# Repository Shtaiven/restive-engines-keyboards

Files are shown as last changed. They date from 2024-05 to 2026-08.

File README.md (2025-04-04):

# restive.engines Keyboards

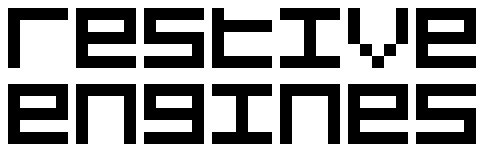
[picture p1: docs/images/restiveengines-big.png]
restiveengines_logo


## Introduction

This repository contains design and manufacturing files created by Steven Eisinger (@Shtaiven a.k.a. restive.engines). Everything you need to manufacture one of my keyboards can be found here, including pcbs, cases, and certain keycaps.

For keyboard firmware, please refer to my [ZMK config repo](https://github.com/Shtaiven/restive-engines-zmk-config).

## Keyboards

### fairyboard

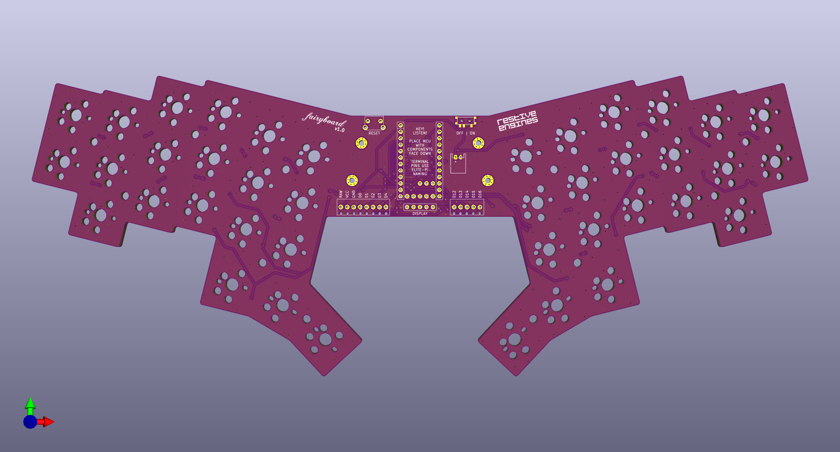
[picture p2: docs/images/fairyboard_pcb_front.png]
fairyboard pcb front


[Build guide](docs/fairyboard.md)

Designed in 2024. Made to address shortcomings and enhance ergonomics of the shockboard. Ergonomic column staggered keyboard extendable with custom modules using terminal blocks or headers. 14 degree rotation on each half. Compatible with MX, Choc v1, and Choc v2 switches.

### shockboard

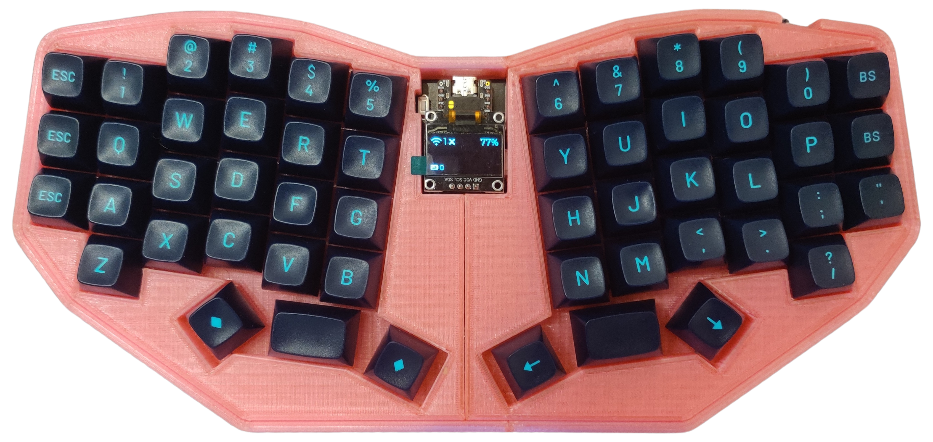
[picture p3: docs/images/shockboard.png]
shockboard_v1_assembled


[Build guide](docs/shockboard.md)

Designed in 2023. My first custom keyboard. Ergonomic column staggered keyboard with a number row, compatible with 1.25u thumb keys. 10 degree rotation on each half. Compatible with MX and Choc v1 switches.

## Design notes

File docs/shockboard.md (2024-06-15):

# shockboard

Assembled shockboard

## Introduction

The shockboard is a monoblock split columnar-staggered keyboard inspired by boards such as the corne, Lily58, Le Chiffre, and others. It is designed based on my own finger positions, with a thumb cluster that is comfortable for my smaller hands while resting in what I consider a neutral position. A monoblock design has been chosen easy portability and setup.

## Manufacturing

### PCB manufacture

See `pcbs/shockboard_v1/shockboard_v1.zip` for files containing pcb fabrication files for each keyboard revision. This zip file can be uploaded to JLCPCB for manufacturing.

### Case manufacture

Only case files for MX switches are currently available in the cases folder.

To print the high profile MX case you will need:

* `cases/shockboard_v1/case_hipro_mx/case_hipro_mx_bottom.stl`
* `cases/shockboard_v1/case_hipro_mx/case_hipro_mx_top.stl`
* `cases/shockboard_v1/pcb_spacer.stl`

These files are provided in both `stl` and `3mf` variants, as well as split into left and right for smaller printers.

## Assembly

### PCB assembly

Materials:

* 1x shockboard PCB
* 1x pro-micro pin compatible microcontroller (nice!nano recommended)
* Mill Max low profile sockets for your micricontroller (see [How do I socket a microcontroller?](https://docs.splitkb.com/hc/en-us/articles/360011263059-How-do-I-socket-a-microcontroller))
* 1x SKHLACA010 footprint compatible button
* 1x MSK12C02 footprint compatible switch
* 52x 1N4148W diodes (SOD-123 surface mount or through-hole)
* 52x CPG151101S11 Kailh hotswap sockets
* 52x MX compatible keyboard switches
* 52x MX compatible keycaps
* 1x SSD1306 OLED display with male and female header pins (optional)
* 1x 301230 LiPo battery with 2-pin JST connector (optional for wireless microcontroller)
* 1x JST 2-pin jack (optional for wireless microcontroller)

Assembling the PCB:

1. Solder the diodes to the back of the PCB (the side with the picture of the cat on it).
2. Solder the Kailh hotswap sockets to the back of the PCB. The hotswap sockets should be oriented such that the bumps fit through the holes and the metal contacts rest on the solder pads.
3. Solder Mill Max low profile female headers to the top side of the PCB in the middle for the microcontroller pins. See [here](https://docs.splitkb.com/hc/en-us/articles/360011263059-How-do-I-socket-a-microcontroller).
4. Socket your microcontroller such that the PCB will lie with its components face-down when attached to the PCB. The microcontroller will be attached from the top of the pcb, so match up the pin labels with those you see on the silkscreen there. See [here](https://docs.splitkb.com/hc/en-us/articles/360011263059-How-do-I-socket-a-microcontroller).
5. Solder the SKHLACA010 button (reset button) to the top of the PCB to the left of the microcontroller.
6. Solder the MSK12C02 switch (power switch) to the top right corner of the PCB.
7. (optional) Solder the 2-pin JST connector to the top side of the board to the right of the microcontroller.
8. (optional) Solder the female headers for the OLED screen to the top side of the board below the microcontroller.
9. (optional) Install the battery into the JST connector and lay in down between the Mill Max headers where the microcontroller will be placed. Make sure that the red battery lead is connected to the left side of the JST jack (marked +) and the black lead is connected to the right side of the JST jack (marked -).
10. Insert the socketed microcontroller with the components faces away from you to the Mill Max sockets.
11. (optional) Insert the OLED display with the pins on the bottom into the female headers.

### Case assembly

Materials:

* 1x case bottom
* 1x case top
* 1x PCB spacer
* 8x m2x8mm screws
* 8x m2 heat-set inserts

Assembling the case:

1. Using a soldering iron, press in the heat-set inserts into the holes of the case bottom from the top-side such that the screws can be screwed in from the top.
2. Create a sandwich with the pieces in the following order from bottom to top:
    1. Case bottom
    2. PCB
    3. PCB spacer
    4. Case top
3. Align the 8 holes of all 4 pieces and screw in the 8 m2 screws from the top of the case until reasonable tight.
4. Insert your favorite switches and keycaps, upload your keyboard firmware, and enjoy!

## Firmware

This keyboard shield has been build with bluetooth-enabled pro-micro compatible boards in mind, like the [nice!nano](https://nicekeyboards.com/nice-nano/).

[ZMK](https://zmk.dev/) support has been added as an [external module](https://zmk.dev/docs/development/build-flash#building-with-external-modules) in my [zmk-config](https://github.com/Shtaiven/shockboard-zmk-config).

For an example of using this with the [miryoku](https://github.com/manna-harbour/miryoku/) layout, see [here](https://github.com/Shtaiven/miryoku_zmk/blob/master/.github/workflows/build.yml).

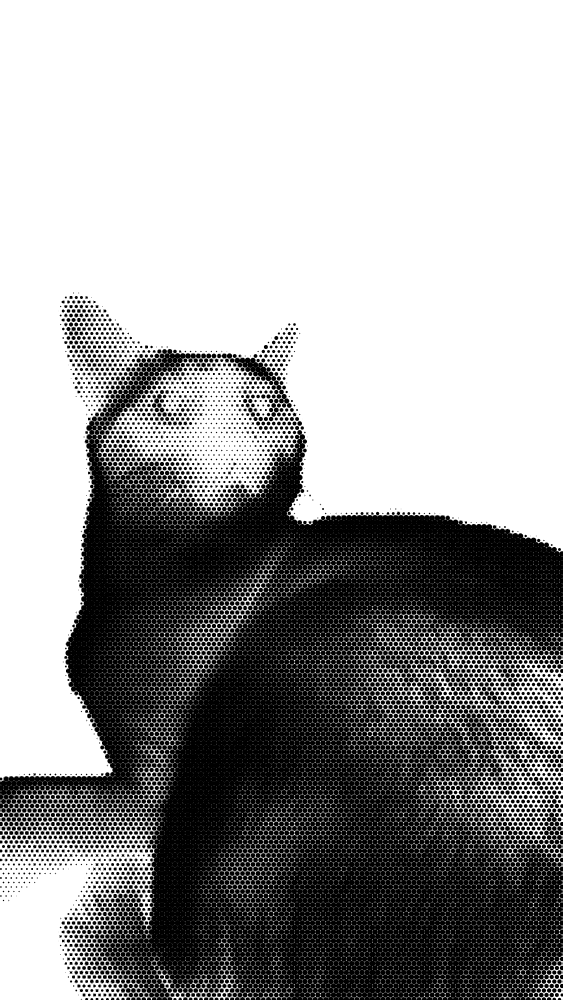
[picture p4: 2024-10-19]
pcbs/images/wumi-stare-halftone.png

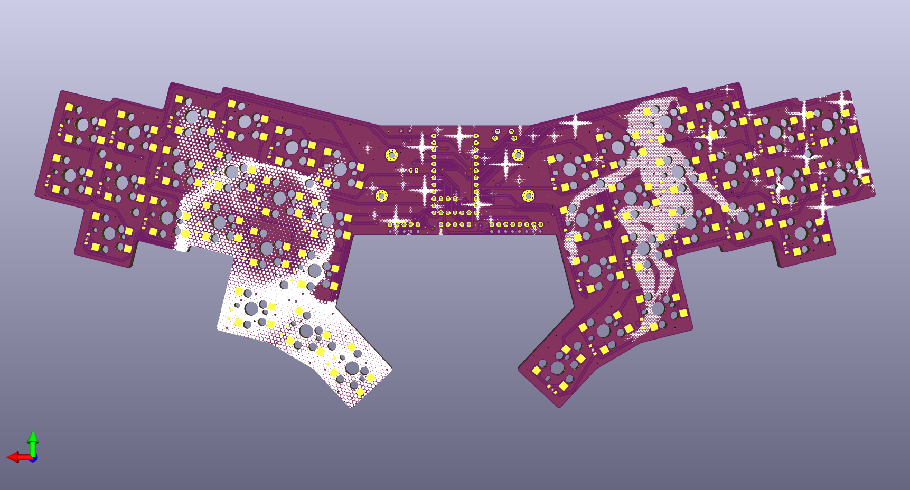
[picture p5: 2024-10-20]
docs/images/fairyboard_pcb_back.png

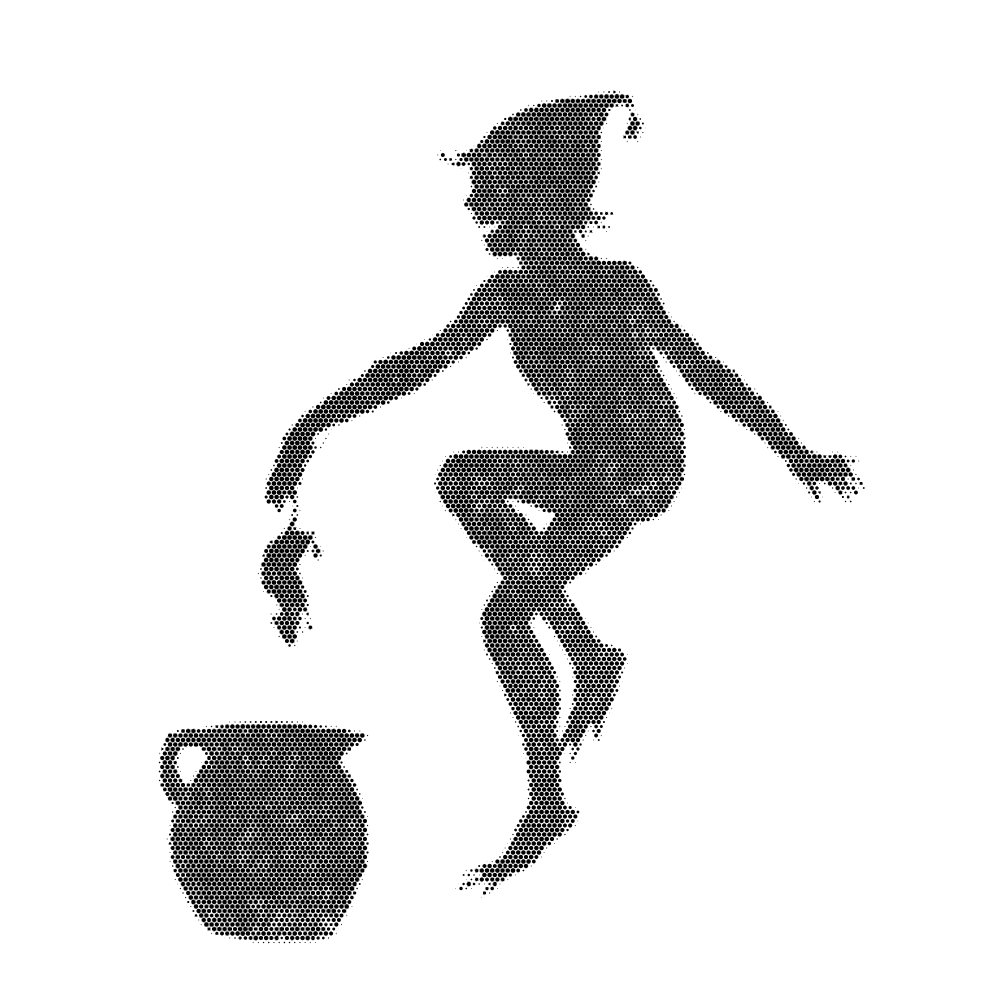
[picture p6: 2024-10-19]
pcbs/images/fairy-halftone.png

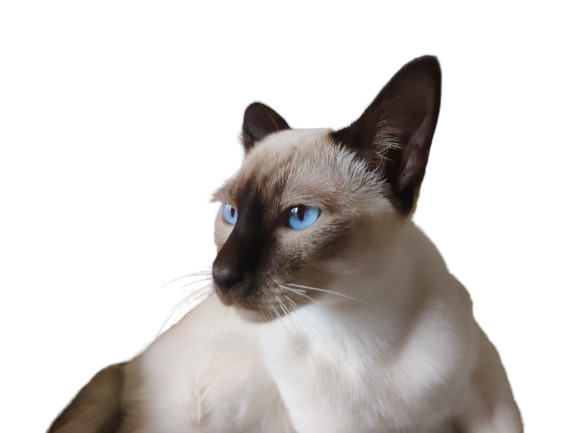
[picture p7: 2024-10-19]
pcbs/images/wumi-removebg.png

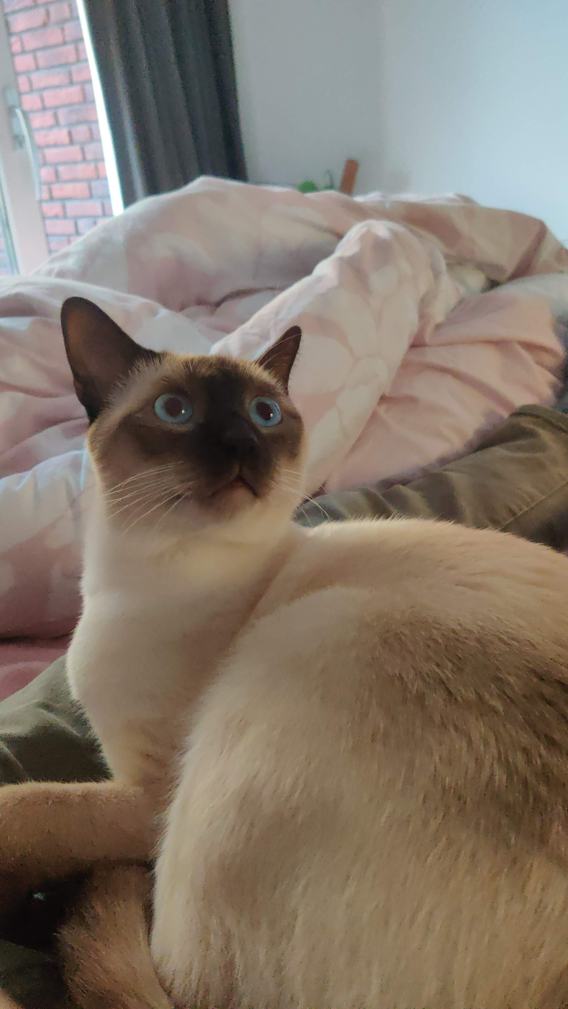
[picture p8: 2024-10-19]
pcbs/images/wumi-stare.jpeg

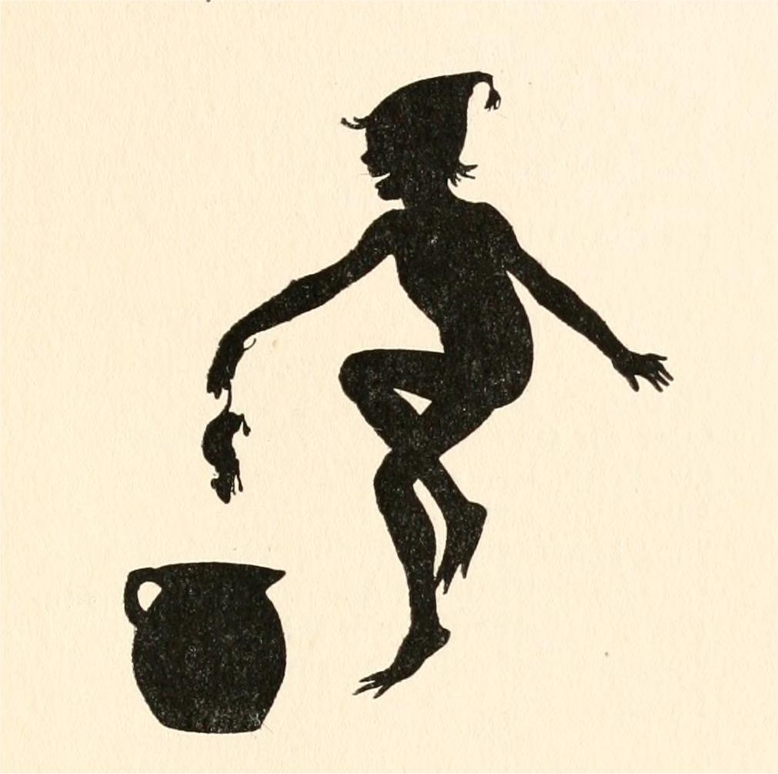
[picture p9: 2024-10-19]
pcbs/images/goble-book-of-fairy-poetry129two-fairies-in-a-garden-cfa38c.jpg

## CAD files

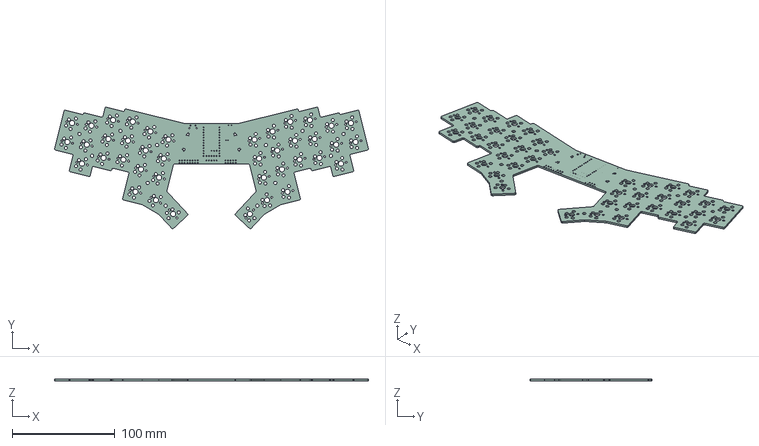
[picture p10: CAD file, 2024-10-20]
pcbs/fairyboard_v1/fairyboard/fairyboard.step
305.6 x 118.3 x 1.60 mm

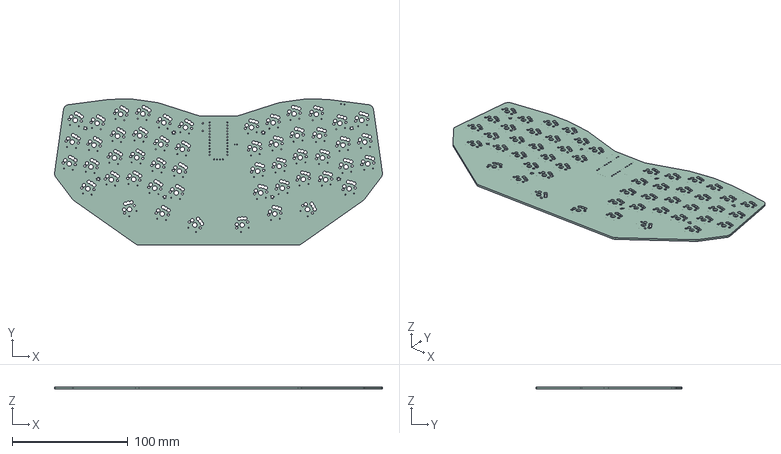
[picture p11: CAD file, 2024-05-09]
pcbs/shockboard_v1/shockboard.step
282.9 x 126.0 x 1.60 mm

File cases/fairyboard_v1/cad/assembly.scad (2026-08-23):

use <fairyboard_v1.scad>
use <top_case.scad>
use <bottom_case.scad>
use <center_window.scad>

$fs = $preview ? 0.5 : 0.1;
$fa = $preview ? 3 : 0.1;

// case or plate
Case_type = 1; // [0:Plate, 1:Low profile case, 2:Spacer case]

// effects case height
Switch_type = 1; // [0:MX, 1:Choc v1, 2:Choc v2]

// threaded insert type for the low profile case
Threaded_insert_type = 0;  // [0:Heatset, 1:Resin]

// outer wall that will hide the pcb
Outer_wall = true;

// thickness of pcb
PCB_thickness = 1.6;

/* [Hidden] */

Color_top_case = "purple";
Top_alpha = 1.0;

Color_bottom_case = "aquamarine";
Bottom_alpha = 1.0;

Color_center_window = "aquamarine";
Window_alpha = 1.0;

Color_pcb = "purple";


//--------------------------------------------------------------------------------
module pcb(thickness=1.6) {
   linear_extrude(PCB_thickness, convexity=5)
    difference() {
        pcb_outline();
        m2_spacers();
        window_mounting_holes();
    }
}


//--------------------------------------------------------------------------------
module case_assembly(case_type, switch_type, pcb_thickness, threaded_insert_type, outer_wall) {
    top_fillet_radius = outer_wall ? 0 : 1.1;
    corner_correction = outer_wall? false : true;
    is_lp_walled = outer_wall && case_type == 1 && switch_type != 0;
    top_overhang = is_lp_walled ? 2*2 : undef;
    
    alpha = 1.0;
    color(Color_top_case, Top_alpha)
    translate([0, 0, pcb_thickness])
    generate_top_case(case_type, switch_type, top_fillet_radius, corner_correction);

    // adjust the center window to be flush with the plate
    center_window_wall_height = switch_type==0 ? 3.5 : 0.7;
    color(Color_center_window, Window_alpha)
    translate([0, 0, pcb_thickness])
    center_window(
        wall_height=center_window_wall_height,
        thickness=1.5,
        hollow=switch_type==0,
        fillet=is_lp_walled ? 0 : 1.1,
        corner_rounding=!is_lp_walled,
        top_overhang=top_overhang
    );
    
    color(Color_pcb)
    pcb(pcb_thickness);
    
    color(Color_bottom_case, Bottom_alpha)
    generate_bottom_case(case_type, switch_type, window_mounting_holes=case_type!=0, threaded_insert_type, bottom_fillet=1.1, outer_wall=outer_wall);
}

case_assembly(Case_type, Switch_type, PCB_thickness, Threaded_insert_type, Outer_wall);

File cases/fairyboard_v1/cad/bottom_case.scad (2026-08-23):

use <fairyboard_v1.scad>
use <hardware.scad>
use <util.scad>
use <center_window.scad>

$fs = $preview ? 0.5 : 0.1;
$fa = $preview ? 3 : 0.1;

// type of case
Case_type = 1; // [0:Plate, 1:Low profile case, 2:Spacer case]

// effects case height for spacer case
Switch_type = 1; // [0:MX, 1:Choc v1, 2:Choc v2]

// threaded insert type for the low profile case
Threaded_insert_type = 0;  // [0:Heatset, 1:Resin]

// bottom fillet radius (default = 1.1)
Bottom_fillet_radius = 1.1;

// place holes for mounting the center window to the bottom
Window_mounting_holes = true;

// outer wall that will hide the pcb
Outer_wall = true;

/* [Hidden] */
Outer_wall_thickness = 1.6;


//--------------------------------------------------------------------------------
/** Create the bottom plate.
 *  Params:
 *    height (float): total height of the bottom plate
 *    bottom_fillet (float): radius of the bottom fillet
 *      requirement height >= bottom_fillet > 0
 *    hole_diameter (float): diameter of the screw holes
 */
module bottom_plate(height=1.5, bottom_fillet=0, hole_diameter=2.4, hole_depth=undef, window_mounting_detents=true, tolerance=0) {
    difference() {
    
        // Create the fillet at the bottom of the plate if wanted
        if (height >= bottom_fillet && bottom_fillet > 0) {
            bottom_fillet(bottom_fillet, height, 0, convexity=5)
            linear_extrude(height, convexity=5)
            offset(delta=tolerance)
            pcb_outline();
        }

        // Simply extrude otherwise
        else {
            linear_extrude(height, convexity=5)
            offset(delta=tolerance)
            pcb_outline();
        }
        
        // Cut out the holes
        translate([0, 0, is_undef(hole_depth) ? -0.01 : height-hole_depth])
        linear_extrude(is_undef(hole_depth) ? height+0.02 : hole_depth, convexity=5)
        offset(r=(hole_diameter-2.4)/2)
        m2_holes();
        
        if (window_mounting_detents) {
            translate([0, 0, is_undef(hole_depth) ? -0.01 : height-hole_depth])
            linear_extrude(is_undef(hole_depth) ? height+0.02 : hole_depth, convexity=5)
            offset(r=(hole_diameter-2.4)/2)
            window_mounting_holes();
        }
    }
}


//--------------------------------------------------------------------------------
/** Cutouts for components which may intersect with the case walls.
 *  Params:
 *    socket_pad_size (float): size of the squares for the hotswap cutouts
 *    diode_size (float): size of the squares for the diode cutouts
 */
module component_cutouts(socket_pad_size=2.6, diode_size=5.2) {
    module left_matrix_sockets_centered(socket_pad_size) {
        // left matrix sockets
        intersection() {
            // region of interest
            difference() {
                translate([-100, 0, 0])
                square([200, 150], center=true);
                
                // middle thumb
                translate([-54, -31, 0])
                rotate([0, 0, -31])
                square([20, 20], center=true);
                
                // inner thumb
                translate([-37.5, -45, 0])
                rotate([0, 0, -47])
                square([20, 20], center=true);
            }
            
            // pads
            offset(delta=-(14-socket_pad_size)/2)
            cutouts_mx();
        }
    }
    module left_thumb_middle_sockets_centered(socket_pad_size) {
        intersection() {
            translate([-54, -31, 0])
            rotate([0, 0, -31])
            square([20, 20], center=true);
            
            offset(delta=-(14-socket_pad_size)/2)
            cutouts_mx();
        }
    }
    module left_thumb_inner_sockets_centered(socket_pad_size) {
        intersection() {
            translate([-37.5, -45, 0])
            rotate([0, 0, -47])
            square([20, 20], center=true);
            
            offset(delta=-(14-socket_pad_size)/2)
            cutouts_mx();
        }
    }
    module right_matrix_sockets_centered(socket_pad_size) {
        intersection() {
            difference() {
                translate([100, 0, 0])
                square([200, 150], center=true);
                
                translate([54, -31, 0])
                rotate([0, 0, 31])
                square([20, 20], center=true);
                
                translate([37.5, -45, 0])
                rotate([0, 0, 47])
                square([20, 20], center=true);
            }
            
            offset(delta=-(14-socket_pad_size)/2)
            cutouts_mx();
        }
    }
    module right_thumb_middle_sockets_centered(socket_pad_size) {
        intersection() {
            translate([54, -31, 0])
            rotate([0, 0, 31])
            square([20, 20], center=true);
            
            offset(delta=-(14-socket_pad_size)/2)
            cutouts_mx();
        }
    }
    module right_thumb_inner_sockets_centered(socket_pad_size) {
        intersection() {
            translate([37.5, -45, 0])
            rotate([0, 0, 47])
            square([20, 20], center=true);
            
            offset(delta=-(14-socket_pad_size)/2)
            cutouts_mx();
        }
    }
    
    // For each region of socket, we will iterate over the 4 hotwap socket pad
    // locations relative to the center of a switch in that region.
    // These are obtained from the kicad pcb
    left_matrix_socket_translations = [
        [-8.937, -1.636, socket_pad_size],  // bottom-left
        [-6.261, 4.178, socket_pad_size],  // top-left
        [6.898, 3.517, socket_pad_size],  // top-right
        [1.737, -6.566, socket_pad_size],  // bottom-right
        [5.885, -5.332, diode_size]  // diode
    ];
    left_thumb_middle_socket_translations = [
        [-9.034, 0.968, socket_pad_size],  // bottom-left
        [-4.815, 5.784, socket_pad_size],  // top-left
        [7.621, 1.413, socket_pad_size],  // top-right
        [-0.199, -6.789, socket_pad_size],  // bottom-right
        [4.128, -6.784, diode_size]  // diode
    ];
    left_thumb_inner_socket_translations = [
        [-8.387, 3.494, socket_pad_size],  // bottom-left
        [-2.974, 6.915, socket_pad_size],  // top-left
        [7.700, -0.807, socket_pad_size],  // top-right
        [-2.119, -6.453, socket_pad_size],  // bottom-right
        [2.031, -7.677, diode_size]  // diode
    ];
    right_matrix_socket_translations = [
        [-7.122, -5.641, socket_pad_size],  // bottom-left
        [-7.490, 0.750, socket_pad_size],  // top-left
        [4.439, 6.343, socket_pad_size],  // top-right
        [4.617, -4.982, socket_pad_size],  // bottom-right
        [7.699, -1.945, diode_size]  // diode
    ];
    right_thumb_middle_socket_translations = [
        [-5.226, 7.432, socket_pad_size],  // bottom-left
        [-7.394, 1.407, socket_pad_size],  // top-left
        [2.455, 7.343, socket_pad_size],  // top-right
        [5.841, -3.465, socket_pad_size],  // bottom-right
        [7.935, 0.322, diode_size]  // diode
    ];
    right_thumb_inner_socket_translations = [
        [-2.900, -8.610, socket_pad_size],  // bottom-left
        [-6.690, -3.449, socket_pad_size],  // top-left
        [0.268, 7.738, socket_pad_size],  // top-right
        [6.585, -1.664, socket_pad_size],  // bottom-right
        [7.517, 2.562, diode_size]  // diode
    ];

    
    for (t=left_matrix_socket_translations) {
        translate([t.x, t.y, 0])
        left_matrix_sockets_centered(t[2]);
    }
    
    for (t=left_thumb_middle_socket_translations) {
        translate([t.x, t.y, 0])
        left_thumb_middle_sockets_centered(t[2]);
    }
    
    for (t=left_thumb_inner_socket_translations) {
        translate([t.x, t.y, 0])
        left_thumb_inner_sockets_centered(t[2]);
    }
    
    for (t=right_matrix_socket_translations) {
        translate([t.x, t.y, 0])
        right_matrix_sockets_centered(t[2]);
    }
    
    for (t=right_thumb_middle_socket_translations) {
        translate([t.x, t.y, 0])
        right_thumb_middle_sockets_centered(t[2]);
    }
    
    for (t=right_thumb_inner_socket_translations) {
        translate([t.x, t.y, 0])
        right_thumb_inner_sockets_centered(t[2]);
    }

    
    // Reset switch
    translate([-18, 5.8675+39.782-5.5, 0])  // 39.782 is height of middle part, 5.5 is height of switch
    square([7.3, 4.5], center=true);
}


//--------------------------------------------------------------------------------
/** Inner cutout of the bottom case for the spacer case.
 *  Params:
 *    height (float): height of the cutout
 */
module bottom_case_inner(height=2, wall_thickness=0.8) {
    linear_extrude(height, convexity=5)
    offset(delta=-wall_thickness)
    pcb_outline();
}
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

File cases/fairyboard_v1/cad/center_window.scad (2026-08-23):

use <fairyboard_v1.scad>
use <util.scad>

$fs = $preview ? 0.5 : 0.1;
$fa = $preview ? 3 : 0.1;

/* [General] */

// plate (flat) or case (featured)
Window_type = 1;  //[0:Plate, 1:Case]

// set to true if you want to export dxf for plate
Projection_2D = false;

/* [Window parameters] */

// height of the outer walls
Wall_height = 0.7;  //[::float]

// height of the circular window
Window_height = 10.0;  //[::float]

// thickness of the shell
Thickness = 1.5;  //[::float]

// fillet radius along the top edges
Top_fillet = 0.0;  //[::float]

// the fillet around the window bump (if present)
Window_bump_fillet = 1.1;  //[::float]

// cutout for a screen if opaque
Screen_cutout = true;

// cutout for an 8-pos terminal block on the left
Terminal8_cutout = true;

// cutout for a 5-pos terminal block on the right
Terminal5_cutout = false;

// cutout in the back for the usb and microcontroller
Usb_cutout=true;

// cutout in the back for the reset button
Reset_button_cutout=true;

// cutout in the back for the power switch
Power_switch_cutout=true;

// cutout for the JST connector
JST_cutout=true;

// hollow out the base shape
Hollow=false;

// round the corners of the base
Corner_rounding=false;

// how much the window should overhang the top (for outer walls)
Top_overhang=2*2;

/* [Hidden] */


//--------------------------------------------------------------------------------
/// Create the base shape of the center window.
module center_window_base(corner_radius=1.1) {
    scale([0.985, 1, 1])
    offset(r=corner_radius)
    offset(delta=-corner_radius)
    board_connector();
}


//--------------------------------------------------------------------------------
/// Create the protruding window shape.
module center_window_inner(top_overhang=undef) {
    if (is_undef(top_overhang)) {
        intersection() {
            translate([0, -23.575, 0])
            center_window_base();

            square([22, 55], center = true); 
        }
    } else {
        // allow a top overhang (helps cover usb port if you have outer walls)
        square([22, 39.78+top_overhang], center = true);
    }
}

//--------------------------------------------------------------------------------
/** Create the center window with a wall and rounded window.
 *  Params:
 *    wall_height (float): height of the outer wall
 *    window_height (float): height of the circular window
 *    thickness (float): thickness of the shell
 *    fillet (float): fillet radius along the top edges
 *    *_cutout (bool): make a cutout for the component if true
 */
module center_window(
    wall_height=3.5,
    window_height=10.0,
    thickness=1.5,
    fillet=1.1,
    window_bump_fillet=1.1,
    screen_cutout=true,
    terminal8_cutout=true,
    terminal5_cutout=false,
    usb_cutout=true,
    reset_button_cutout=true,
    power_switch_cutout=true,
    jst_cutout=true,
    hollow=true,
    corner_rounding=true,
    top_overhang=undef
) {
    max_window_fillet = 4;
    calculated_window_fillet = min(window_height-wall_height, max_window_fillet);
    
    top_window_fillet = is_undef(window_bump_fillet) ? calculated_window_fillet : window_bump_fillet;
    difference() {
        union() {
            // Create the main hollowed window shape
            top_fillet(fillet, wall_height+thickness, 0)
            linear_extrude(thickness+wall_height, convexity=5)
            center_window_base(corner_rounding ? 1.1 : 0);
            
            // Create the window bump
            if (window_height > wall_height) {
                translate([0, 23.575, wall_height+thickness])
                top_fillet(top_window_fillet, window_height-wall_height, 0)
                linear_extrude(window_height-wall_height)
                center_window_inner(top_overhang);
            }
            
            if (jst_cutout) {
                // pad out the wire bump because it's too thin (usually only 1 layer on a 3d printer (JST connector is 2mm high)
                wire_cover = [9, 12.1, 2];
                translate([10, bottom_offset+3, thickness+wall_height])
                top_fillet(top_window_fillet, wire_cover.z, 0)
                cube(wire_cover);
            }
        }

        // Hollow out the base shape
        if (wall_height > 0 && hollow) {
            translate([0, 0, -0.01])
            linear_extrude(wall_height+0.01, convexity=5)
            offset(delta=-thickness)
            center_window_base();
        }
        
        // Hollow out the window bump
        if (window_height > wall_height) {
            space_for_pcb = 1.6;
            translate([0, 23.575+space_for_pcb/2, 0]) // make some roo
            linear_extrude(window_height)
            offset(delta=-thickness)
            center_window_inner(space_for_pcb);
        }
        
        // Mounting hole cutouts
        translate([0, 0, -0.01])
        linear_extrude(window_height+thickness+0.02)
        window_mounting_holes();

        bottom_offset = 3.68;  // y-offset of the "bottom" of the window
        
        // Terminal cutouts
        if (terminal8_cutout) {
            translate([-11, bottom_offset, -0.01])
            mirror([1, 0, 0])
            // extra x added to chop off the thin bit left over
            cube([25.88, 7.4, window_height+thickness+0.02]);
        }

        if (terminal5_cutout) {
            translate([11.84, bottom_offset, -0.01])
            cube([13.26, 7.4, window_height+thickness+0.02]);
        }
        
        top_edge_offset = 43.47;
        
        // USB cutout
        if (usb_cutout) {
            usb_overhang = is_undef(top_overhang) ? 0.0 : top_overhang;
            
            // A large inner cavity compatible without a top overhang
            // which won't pinch the nice_view screen
            usb_dims = [19, 8.5+window_bump_fillet];
            translate([-usb_dims.x/2, top_edge_offset-thickness-0.25, 0])
            rotate([90, 0 ,0])
            linear_extrude(thickness+2, center=true)
            //offset(r=window_bump_fillet)
            //offset(delta=-window_bump_fillet)
            square([19, wall_height+thickness]);
            
            // A cutout more tightly surround the usb-c connector
            // in the presence of a top overhang
            nice_nano_usbc_height = 4.3;
            hull() {
                translate([0, top_edge_offset+usb_overhang/4, nice_nano_usbc_height])
                rotate([90, 0 ,0])
                linear_extrude(thickness+usb_overhang+1, center=true)
                usbc_cutout();
                
                translate([0, top_edge_offset+usb_overhang/4])
                rotate([90, 0 ,0])
                linear_extrude(thickness+usb_overhang+1, center=true)
                usbc_cutout();
            }
        }
        
        // Slide switch cutout
        if (power_switch_cutout) {
            pwr_sw_size = [9.2, 9, 3];
            translate([13.45, top_edge_offset+1, 0])
            mirror([0, 1, 0])
            cube(pwr_sw_size);
        }
        
        // Reset button cutout
        if (reset_button_cutout) {
            reset_btn_size = [8.5, 9, 5];
            translate([-13.55, top_edge_offset+1, 0])
            mirror([1, 1, 0])
            cube(reset_btn_size);
        }
        
        // JST (battery) cutout
        if (jst_cutout) {
            jst_size = [8, 11, 6];
            translate([11, bottom_offset+14, 0])
            cube(jst_size);
            
            // space for wires
            wires_size = [9, 10, 1.6];
            translate([9, bottom_offset+4, 0])
            cube(wires_size);
        }
        
        // Optional screen cutout
        if (screen_cutout) {
            // Chamfered screen cutout
            screen_dims = [12, 26];
            top_chamfer = [22-window_bump_fillet*2-1, 43.5-window_bump_fillet*2-1];
            window_step_size = [
                (top_chamfer.x-screen_dims.x),
                (top_chamfer.y-screen_dims.y)
            ];
            bottom_chamfer = top_chamfer-window_step_size;
            chamfer_depth = thickness/2;
            translate([0, (bottom_offset+top_edge_offset)/2, window_height+chamfer_depth-0.03])
            chamfered_rectangle(top_chamfer, bottom_chamfer, chamfer_depth+0.03);
            
            // Give it some thickness so it doesn't end on the sharp edge
            translate([0, (bottom_offset+top_edge_offset)/2, window_height-0.03])
            cube([screen_dims.x, screen_dims.y, thickness], center=true);
        }
    }
}
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

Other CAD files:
cases/fairyboard_v1/outlines/window_mounting_holes.dxf
cases/fairyboard_v1/plate_case/top_plate_choc_v1.stl
cases/fairyboard_v1/slim_case/bottom_case_lowpro_window_mounting_left.3mf
cases/fairyboard_v1/slim_case_with_walls/bottom_case.3mf
cases/shockboard_v1/case_hipro_mx/case_hipro_mx_bottom_right.3mf
cases/shockboard_v1/case_lopro_mx/case_lopro_mx_bottom.3mf
cases/shockboard_v1/pcb_spacer_right.3mf
ergogen/fairyboard_v1/output/cases/plate_mx.stl
ergogen/fairyboard_v1/output/outlines/window_mounting_holes.dxf
ergogen/shockboard_v1/output/cases/mounting_holes.stl
ergogen/shockboard_v1/output/outlines/keywell_mx.dxf
keycaps/chicago_stenographer/cs_row_thumbs.stl
cases/fairyboard_v1/outlines/cutouts_extension.dxf
cases/fairyboard_v1/plate_case/bottom_plate.stl
cases/fairyboard_v1/slim_case/bottom_case_lowpro_window_mounting_right.3mf
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

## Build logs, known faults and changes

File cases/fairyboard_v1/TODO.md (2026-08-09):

# CAD TODOs

## center_window.scad

- Make sure the wall around the screen will keep it in place

## bottom_case.scad

## top_case.scad

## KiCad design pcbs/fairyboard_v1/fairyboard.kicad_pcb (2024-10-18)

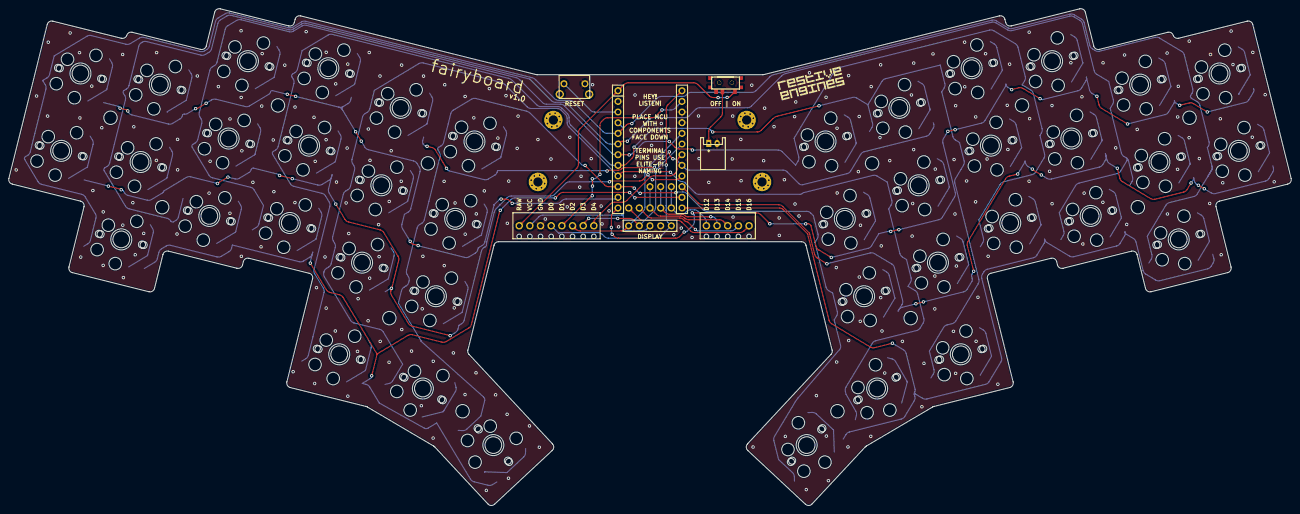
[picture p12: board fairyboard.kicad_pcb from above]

Board: 2 copper layers, 305.6 x 118.3 mm, 142 parts (0 on the bottom side), 60 nets.

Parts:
D1, D2, D3, D4, D5, D6, D7, D8, D9, D10, D11, D12, D13, D14, D15, D16, D17, D18, D19, D20, D21, D22, D23, D24, D25, D26, D27, D28, D29, D30, D31, D32, D33, D34, D35, D36, D37, D38, D39, D40: SmtDiode
DISP1: display_nice_view
JST1: JST_PH_S2B-PH-K_02x2.00mm_Angled
RST1: reset_switch_tht_side
S1, S2, S3, S4, S5, S6, S7, S8, S9, S10, S11, S12, S13, S14, S15, S16, S17, S18, S19, S20, S21, S22, S23, S24, S25, S26, S27, S28, S29, S30, S31, S32, S33, S34, S35, S36, S37, S38, S39, S40: MX
S41, S42, S43, S44, S45, S46, S47, S48, S49, S50, S51, S52, S53, S54, S55, S56, S57, S58, S59, S60, S61, S62, S63, S64, S65, S66, S67, S68, S69, S70, S71, S72, S73, S74, S75, S76, S77, S78, S79, S80: PG1350
T1: SPDT_C128955
TERMINAL1: terminal_block_8
TERMINAL2: terminal_block_5
_2, _3, _4, _5, _6, _7, _8, _9, _10, _11, _12, _13: SpacerHole_3.2mm_M2_Pad_Via
_14, _15, _16, _17: MountingHole_2.2mm_M2_Pad_Via

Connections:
B+: JST1.1, T1.2
COL1: S1.1, S2.1, S3.1, S21.1, S22.1, S23.1, S41.2, S42.2, S43.2, S61.2, S62.2, S63.2
COL2: S4.1, S5.1, S6.1, S24.1, S25.1, S26.1, S44.2, S45.2, S46.2, S64.2, S65.2, S66.2
COL3: S7.1, S8.1, S9.1, S27.1, S28.1, S29.1, S37.1, S47.2, S48.2, S49.2, S67.2, S68.2, S69.2, S77.2
COL4: S10.1, S11.1, S18.1, S30.1, S31.1, S34.1, S38.1, S50.2, S51.2, S58.2, S70.2, S71.2, S74.2, S78.2
COL5: S12.1, S13.1, S14.1, S19.1, S32.1, S33.1, S39.1, S52.2, S53.2, S54.2, S59.2, S72.2, S73.2, S79.2
COL6: S15.1, S16.1, S17.1, S20.1, S35.1, S36.1, S40.1, S55.2, S56.2, S57.2, S60.2, S75.2, S76.2, S80.2
D0: DISP1.5, TERMINAL1.4
D2: DISP1.1, TERMINAL1.6
D3: DISP1.2, TERMINAL1.7
GND: DISP1.4, JST1.2, RST1.1, TERMINAL1.3
RAW: T1.1, TERMINAL1.1
ROW1: D14.1, D17.1, D34.1, D37.1
ROW2: D2.1, D5.1, D8.1, D11.1, D13.1, D16.1
ROW3: D1.1, D4.1, D7.1, D10.1, D12.1, D15.1
ROW4: D3.1, D6.1, D9.1, D18.1, D19.1, D20.1
ROW5: D22.1, D25.1, D28.1, D31.1, D33.1, D36.1
ROW6: D21.1, D24.1, D27.1, D30.1, D32.1, D35.1
ROW7: D23.1, D26.1, D29.1, D38.1, D39.1, D40.1
VCC: DISP1.3, TERMINAL1.2
index_bottom: D12.2, S12.2, S52.1
index_home: D13.2, S13.2, S53.1
index_top: D14.2, S14.2, S54.1
inner_bottom: D15.2, S15.2, S55.1
inner_home: D16.2, S16.2, S56.1
inner_thumb: D20.2, S20.2, S60.1
inner_top: D17.2, S17.2, S57.1
middle_bottom: D9.2, S9.2, S49.1
middle_home: D10.2, S10.2, S50.1
middle_thumb: D19.2, S19.2, S59.1
middle_top: D11.2, S11.2, S51.1
mirror_index_bottom: D32.2, S32.2, S72.1
mirror_index_home: D33.2, S33.2, S73.1
mirror_index_top: D34.2, S34.2, S74.1
mirror_inner_bottom: D35.2, S35.2, S75.1
mirror_inner_home: D36.2, S36.2, S76.1
mirror_inner_thumb: D40.2, S40.2, S80.1
mirror_inner_top: D37.2, S37.2, S77.1
mirror_middle_bottom: D29.2, S29.2, S69.1
mirror_middle_home: D30.2, S30.2, S70.1
mirror_middle_thumb: D39.2, S39.2, S79.1
mirror_middle_top: D31.2, S31.2, S71.1
mirror_outer_home: D21.2, S21.2, S61.1
mirror_outer_thumb: D38.2, S38.2, S78.1
mirror_outer_top: D22.2, S22.2, S62.1
mirror_pinky_bottom: D23.2, S23.2, S63.1
mirror_pinky_home: D24.2, S24.2, S64.1
mirror_pinky_top: D25.2, S25.2, S65.1
mirror_ring_bottom: D26.2, S26.2, S66.1
mirror_ring_home: D27.2, S27.2, S67.1
mirror_ring_top: D28.2, S28.2, S68.1
outer_home: D1.2, S1.2, S41.1
outer_thumb: D18.2, S18.2, S58.1
outer_top: D2.2, S2.2, S42.1
pinky_bottom: D3.2, S3.2, S43.1
pinky_home: D4.2, S4.2, S44.1
pinky_top: D5.2, S5.2, S45.1
ring_bottom: D6.2, S6.2, S46.1
ring_home: D7.2, S7.2, S47.1
ring_top: D8.2, S8.2, S48.1

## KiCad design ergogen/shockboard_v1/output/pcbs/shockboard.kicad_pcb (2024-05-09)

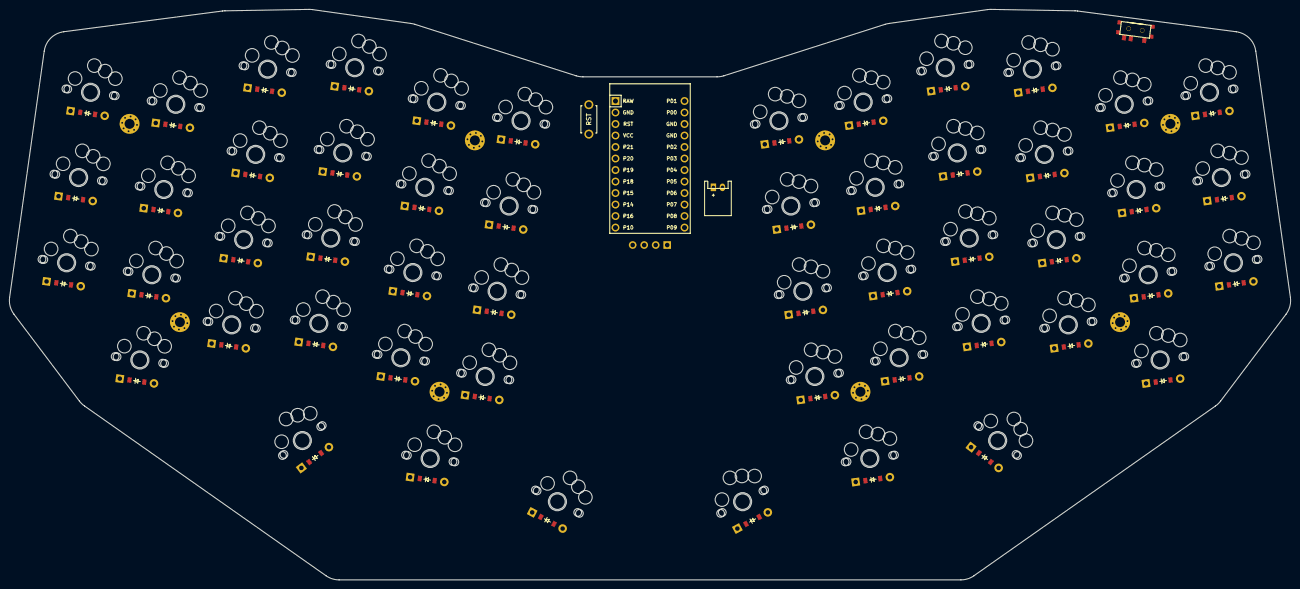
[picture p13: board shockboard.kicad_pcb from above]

Board: 2 copper layers, 282.9 x 126.0 mm, 169 parts (0 on the bottom side), 75 nets, no tracks yet.

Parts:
D1, D2, D3, D4, D5, D6, D7, D8, D9, D10, D11, D12, D13, D14, D15, D16, D17, D18, D19, D20, D21, D22, D23, D24, D25, D26, D27, D28, D29, D30, D31, D32, D33, D34, D35, D36, D37, D38, D39, D40, D41, D42, D43, D44, D45, D46, D47, D48, D49, D50, D51, D52: ComboDiode
JST1: JST_PH_S2B-PH-K_02x2.00mm_Angled
MCU1: ProMicro
OLED1: OLED; OLED_headers
RST1: reset_switch_tht_top
S1, S2, S3, S4, S5, S6, S7, S8, S9, S10, S11, S12, S13, S14, S15, S16, S17, S18, S19, S20, S21, S22, S23, S24, S25, S26, S27, S28, S29, S30, S31, S32, S33, S34, S35, S36, S37, S38, S39, S40, S41, S42, S43, S44, S45, S46, S47, S48, S49, S50, S51, S52: MX
S53, S54, S55, S56, S57, S58, S59, S60, S61, S62, S63, S64, S65, S66, S67, S68, S69, S70, S71, S72, S73, S74, S75, S76, S77, S78, S79, S80, S81, S82, S83, S84, S85, S86, S87, S88, S89, S90, S91, S92, S93, S94, S95, S96, S97, S98, S99, S100, S101, S102, S103, S104: PG1350
T1: SPDT_C128955
_1, _2, _3, _4, _5, _6, _7, _8: MountingHole_2.2mm_M2_Pad_Via

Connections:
B+: JST1.1, T1.2
GND: JST1.2, MCU1.2, MCU1.15, MCU1.16, OLED1.1, RST1.2
P0: D27.1, D31.1, D35.1, D39.1, D43.1, D47.1, MCU1.14
P1: D30.1, D34.1, D38.1, D42.1, D46.1, MCU1.13
P2: MCU1.17, OLED1.4
P3: MCU1.18, OLED1.3
P4: D28.1, D32.1, D36.1, D40.1, D44.1, D48.1, MCU1.19
P5: D29.1, D33.1, D37.1, D41.1, D45.1, D49.1, MCU1.20
P6: D50.1, D51.1, D52.1, MCU1.21
P7: MCU1.22, S12.1, S13.1, S14.1, S15.1, S24.1, S38.1, S39.1, S40.1, S41.1, S50.1, S64.1, S65.1, S66.1, S67.1, S76.1, S90.1, S91.1, S92.1, S93.1, S102.1
P8: MCU1.23, S16.1, S17.1, S18.1, S19.1, S25.1, S42.1, S43.1, S44.1, S45.1, S51.1, S68.1, S69.1, S70.1, S71.1, S77.1, S94.1, S95.1, S96.1, S97.1, S103.1
P9: MCU1.24, S20.1, S21.1, S22.1, S23.1, S26.1, S46.1, S47.1, S48.1, S49.1, S52.1, S72.1, S73.1, S74.1, S75.1, S78.1, S98.1, S99.1, S100.1, S101.1, S104.1
P10: MCU1.12, S8.1, S9.1, S10.1, S11.1, S34.1, S35.1, S36.1, S37.1, S60.1, S61.1, S62.1, S63.1, S86.1, S87.1, S88.1, S89.1
P14: MCU1.10, S1.1, S2.1, S3.1, S27.1, S28.1, S29.1, S53.1, S54.1, S55.1, S79.1, S80.1, S81.1
P15: D24.1, D25.1, D26.1, MCU1.9
P16: MCU1.11, S4.1, S5.1, S6.1, S7.1, S30.1, S31.1, S32.1, S33.1, S56.1, S57.1, S58.1, S59.1, S82.1, S83.1, S84.1, S85.1
P18: D3.1, D7.1, D11.1, D15.1, D19.1, D23.1, MCU1.8
P19: D2.1, D6.1, D10.1, D14.1, D18.1, D22.1, MCU1.7
P20: D1.1, D5.1, D9.1, D13.1, D17.1, D21.1, MCU1.6
P21: D4.1, D8.1, D12.1, D16.1, D20.1, MCU1.5
RAW: MCU1.1, T1.1
RST: MCU1.3, RST1.1
VCC: MCU1.4, OLED1.2
index_bottom: D16.2, S16.2, S68.2
index_home: D17.2, S17.2, S69.2
index_num: D19.2, S19.2, S71.2
index_top: D18.2, S18.2, S70.2
inner_bottom: D20.2, S20.2, S72.2
inner_home: D21.2, S21.2, S73.2
inner_num: D23.2, S23.2, S75.2
inner_thumb: D26.2, S26.2, S78.2
inner_top: D22.2, S22.2, S74.2
middle_bottom: D12.2, S12.2, S64.2
middle_home: D13.2, S13.2, S65.2
middle_num: D15.2, S15.2, S67.2
middle_thumb: D25.2, S25.2, S77.2
middle_top: D14.2, S14.2, S66.2
mirror_index_bottom: D42.2, S42.2, S94.2
mirror_index_home: D43.2, S43.2, S95.2
mirror_index_num: D45.2, S45.2, S97.2
mirror_index_top: D44.2, S44.2, S96.2
mirror_inner_bottom: D46.2, S46.2, S98.2
mirror_inner_home: D47.2, S47.2, S99.2
mirror_inner_num: D49.2, S49.2, S101.2
mirror_inner_thumb: D52.2, S52.2, S104.2
mirror_inner_top: D48.2, S48.2, S100.2
mirror_middle_bottom: D38.2, S38.2, S90.2
mirror_middle_home: D39.2, S39.2, S91.2
mirror_middle_num: D41.2, S41.2, S93.2
mirror_middle_thumb: D51.2, S51.2, S103.2
mirror_middle_top: D40.2, S40.2, S92.2
mirror_outer_home: D27.2, S27.2, S79.2
mirror_outer_num: D29.2, S29.2, S81.2
mirror_outer_thumb: D50.2, S50.2, S102.2
mirror_outer_top: D28.2, S28.2, S80.2
mirror_pinky_bottom: D30.2, S30.2, S82.2
mirror_pinky_home: D31.2, S31.2, S83.2
mirror_pinky_num: D33.2, S33.2, S85.2
mirror_pinky_top: D32.2, S32.2, S84.2
mirror_ring_bottom: D34.2, S34.2, S86.2
mirror_ring_home: D35.2, S35.2, S87.2
mirror_ring_num: D37.2, S37.2, S89.2
mirror_ring_top: D36.2, S36.2, S88.2
outer_home: D1.2, S1.2, S53.2
outer_num: D3.2, S3.2, S55.2
outer_thumb: D24.2, S24.2, S76.2
outer_top: D2.2, S2.2, S54.2
pinky_bottom: D4.2, S4.2, S56.2
pinky_home: D5.2, S5.2, S57.2
pinky_num: D7.2, S7.2, S59.2
pinky_top: D6.2, S6.2, S58.2
ring_bottom: D8.2, S8.2, S60.2
ring_home: D9.2, S9.2, S61.2
ring_num: D11.2, S11.2, S63.2
ring_top: D10.2, S10.2, S62.2

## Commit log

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2021-11-23 Changed directory structure, made second half of the keyboard, added nicenano
    [layout_cherry.dxf, shckb.sch, shockboard.kicad_pcb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]
2022-06-14 Added new kicad file format and preliminary ergogen layout
    [shockboard.kicad_pcb, shockboard.kicad_sch]
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2022-10-13 Added lots of files used for the 3d model
    [shockboard.kicad_pcb, shockboard_extrude.FCStd, shockboard_test.stl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]
2022-10-18 feat: started adjusting v0.2 layout. Reorganized some folders
    [shockboard_test.stl, shockboard_test_half.stl]
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2022-10-21 Added svg files for fab and changed to M3 screws
    [plate_bent.dxf]
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2024-02-09 feat: corrected nets for rows and columns
    [mx_cutouts.dxf, raw.dxf, shockboard.kicad_pcb]
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2024-03-10 wip: outline redesign
    [mx_cutouts.dxf, mx_plate.dxf, raw.dxf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]
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2024-03-17 feat: slightly flatter bottom and slightly tighter choc plates
    [choc_cutouts.dxf, choc_plate_mx.dxf, mx_plate.dxf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]
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2024-04-13 feat: replace ecad with the current ergogen output v0.4.0
    [choc_cutouts.dxf, choc_plate_mx.dxf, layout_cherry.dxf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]
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2024-04-14 wip: routing and fill, missing ground plane vias and silkscreen
    [shockboard.kicad_pcb]
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2024-04-16 feat: complete board with fab, no silkscreen yet
    [shockboard-B_Cu.gbl, shockboard-B_Mask.gbs, shockboard-B_Paste.gbp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]
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2024-04-20 feat: cleaned up minimal case and config a bit
    [board.dxf, case.stl, padded_board.dxf]
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2024-05-09 wip: top and bottom hipro case in openscad (missing some holes)
    [case_hipro_mx_bottom.scad, case_hipro_mx_top.scad, fillets2d.scad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]
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2024-05-11 feat: added screws, standoffs, and inserts and corrected assembly
    [assembly.scad, case_hipro_mx_bottom.scad, case_hipro_mx_top.scad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]
2024-05-11 feat: add hole in top case for promicro and screen
    [case_hipro_mx_top.scad, promicro_cutout.dxf, shockboard_v1.scad]
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2024-05-12 fix: add 1mm clearance to case hipro bottom mx
    [assembly.scad, case_hipro_mx_bottom.scad, case_hipro_mx_bottom.stl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]
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2024-05-14 feat: adjusted hipro mx case for better tolerances and correct heatset insert sizes. Added lowpro mx case.
    [assembly_hipro_mx.scad, assembly_lopro_mx.scad, case_bottom.scad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]
2024-05-15 feat: generate models and remove old fab files
    [assembly_hipro_mx.scad, assembly_lopro_mx.scad, case_hipro_mx_bottom.3mf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]
2024-05-18 feat: space for cable around board edge for nice view
    [assembly_hipro_mx.scad, case_bottom.scad, case_hipro_mx_bottom.3mf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]
2024-05-20 feat: test config for printing and overhang on bottom cases
    [case_bottom.scad, case_hipro_mx_bottom.3mf, case_hipro_mx_bottom.stl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]
2024-05-20 feat: remove unneeded parts and added split hipro case stls
    [case_hipro_mx_bottom_left.stl, case_hipro_mx_bottom_right.stl, test_part.3mf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]
2024-05-26 misc: update scad files for better support under pcb and wider thumb keywell
    [assembly_hipro_mx.scad, case_bottom.scad, case_hipro_mx_top.scad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]
2024-05-28 feat: fixes for thumb keywell and added a pcb spacer
    [assembly_hipro_mx.scad, assembly_lopro_mx.scad, keywell_mx.dxf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]
2024-06-02 feat: added internal support structure to cases and added pcb spacer
    [case_hipro_mx_bottom.3mf, case_hipro_mx_bottom.stl, case_hipro_mx_bottom_left.stl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]
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2024-06-21 feat: move footprints dir to be common between boards and generate first fairyboard
    [battery_switch_cutout.dxf, board.dxf, case_outline.dxf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]
2024-06-21 feat: modified rotation, thumb cluster, and split distance
    [battery_switch_cutout.dxf, board.dxf, case_outline.dxf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]
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2024-06-22 wip: invert choc hotswap and move diodes
    [fairyboard.kicad_pcb]
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2024-07-25 feat: remove top row and modify thumb cluster
    [battery_switch_cutout.dxf, board.dxf, case_outline.dxf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]
2024-08-05 feat: prototyping shape of fairyboard and added key position adjustments to ergogen
    [battery_switch_cutout.dxf, board.dxf, case_outline.dxf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]
2024-08-19 feat: adjust stagger on outer and inner column
    [battery_switch_cutout.dxf, board.dxf, case_outline.dxf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]
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2024-08-20 feat: remove a large blank space near board bottom
    [board.dxf, board_raw.dxf, case_outline.dxf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]
2024-08-20 feat: reverse column and row net of inverted chocs
    [board.dxf, board_raw.dxf, case_outline.dxf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]
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2024-09-25 feat: create spacerhole and move them to appropriate positions
    [fairyboard.kicad_pcb]
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2024-09-26 fix: VIK OUT instead of VIK IN
    [fairyboard.kicad_pcb]
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2024-09-28 fix: adjust bottom mounting holes
    [fairyboard.kicad_pcb]
2024-09-29 feat: increase fillet size to prevent DRC error
    [board.dxf, case_outline.dxf, fairyboard.kicad_pcb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]
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2024-10-02 feat: correct flipped silkscreen
    [fairyboard.kicad_pcb]
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2024-10-05 feat: move mounting hole for screen up and make silkscreen visible for terminal_block
    [fairyboard.kicad_pcb]
2024-10-06 misc: move labels of terminal block a bit up
    [fairyboard.kicad_pcb]
2024-10-06 misc: correct nets for all rows and columns
    [fairyboard.kicad_pcb]
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2024-10-06 misc: adjust spacer hole clearance
    [fairyboard.kicad_pcb]
2024-10-07 misc: correct pin order on mcu
    [fairyboard.kicad_pcb]
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2024-10-07 feat: simple cases (missing cutouts)
    [battery_switch_cutout.dxf, case_hipro_mx.stl, case_lowpro.stl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]
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2024-10-09 feat: minor adjustments to component placement and switch D5 for D1 as default cs pin
    [fairyboard.kicad_pcb]
2024-10-10 misc: move jst connector up and fix - character
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2024-10-10 feat: added terminal block for extra pins and rearranged terminal block pins
    [fairyboard.kicad_pcb]
2024-10-10 feat: save and move pcb to pcbs folder
    [fairyboard.kicad_pcb]
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2024-10-13 feat: adjustments to top of pcb and silkscreen
    [fairyboard.kicad_pcb]
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2024-10-18 fix: border outline
    [fairyboard.kicad_pcb]
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2024-10-20 misc: cleanup unused pyproject and add step file
    [fairyboard.step]
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2024-10-23 feat: added some construction outlines for future cad work
    [cutouts_extension.dxf, fairyboard_v1.scad, m2_spacers.dxf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]
2024-10-24 feat: consolidate top case/plate cad and create top cases
    [cutouts_extension.dxf, top_case.scad, top_case_choc_v1.stl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]
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2024-11-02 feat: added choc v2 top case print files
    [top_case_choc_v2_left.3mf, top_case_choc_v2_right.3mf]
2024-11-03 feat: complete bottom case and top case refactor
    [bottom_case.scad, top_case.scad]
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2024-11-24 feat: modify the center window to be lower profile and generate several versions (case and plate)
    [assembly.scad, center_plate_with_screen_terminal8_cutout.dxf, center_plate_with_screen_terminal8_cutout.stl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]
2024-12-01 feat: cleanup and fix SCUF bumpons
    [assembly.scad, bottom_case.scad, bottom_case_choc_v1.stl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]
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2025-03-21 feat: correct inserts for resin
    [bottom_case.scad]
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2026-05-03 fix: center window doesn't start with number
    [center_window.scad]
2026-05-03 feat: cutouts for power, reset, terminal on bottom case with wall
    [assembly.scad, bottom_case.scad, center_window.scad]
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2026-05-04 feat: center window remove roundedness and fix top case for slim with walls
    [assembly.scad, center_window.scad, top_case.stl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]
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2026-05-09 feat: 3mf files for new center window and bottom hase for slim lp with walls
    [bottom_case_left.3mf, bottom_case_right.3mf, center_window.3mf]
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2026-08-08 feat: increase the low profile case by 1mm height and remove the towers around the heat set inserts
    [bottom_case.scad]
2026-08-09 feat: widen spacer for slim wall case and generate files for it
    [spacer.dxf, spacer.stl, top_case.scad]
2026-08-09 misc: re-export plate, spacer, center window without rounding, and re-export bottom case
    [bottom_case.stl, center_window.stl, plate.dxf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]
2026-08-22 misc: increase usbc cutout tolerance, nudge other cutouts, chamfer window to screen outline
    [bottom_case_left.3mf, bottom_case_right.3mf, center_window.3mf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]
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2026-08-22 misc: reinforcement over jst wie cutout
    [center_window.3mf, center_window.scad, center_window.stl]
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2026-08-23 fix: proper spacing for usb, ~2mm walls around case, and bottom case matches window cutouts
    [assembly.scad, bottom_case.scad, bottom_case.stl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]
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2026-09-13 feat: updated holes of pcb plate to be 2.4mm diameter instead of 2.2
    [fairyboard_plate-B_Cu.gbl, fairyboard_plate-B_Mask.gbs, fairyboard_plate-B_Paste.gbp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]
